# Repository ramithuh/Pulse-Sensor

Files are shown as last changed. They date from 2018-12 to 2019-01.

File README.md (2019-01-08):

#### EN1093 - Laboratory Practice - Group Project 



[https://blog.ramith.fyi/static/creating-a-pulse-sensor-from-scratch](https://blog.ramith.fyi/static/creating-a-pulse-sensor-from-scratch)

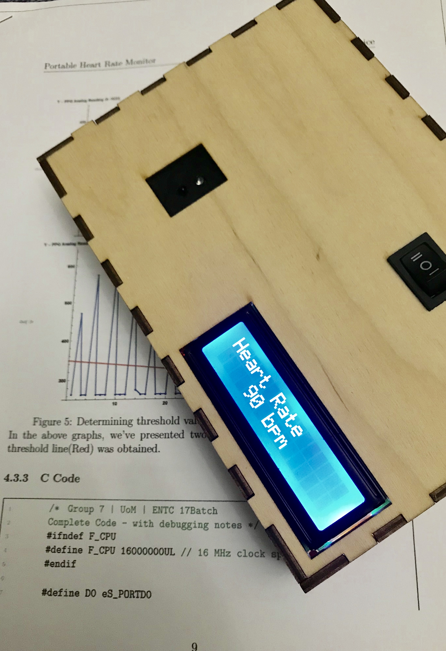
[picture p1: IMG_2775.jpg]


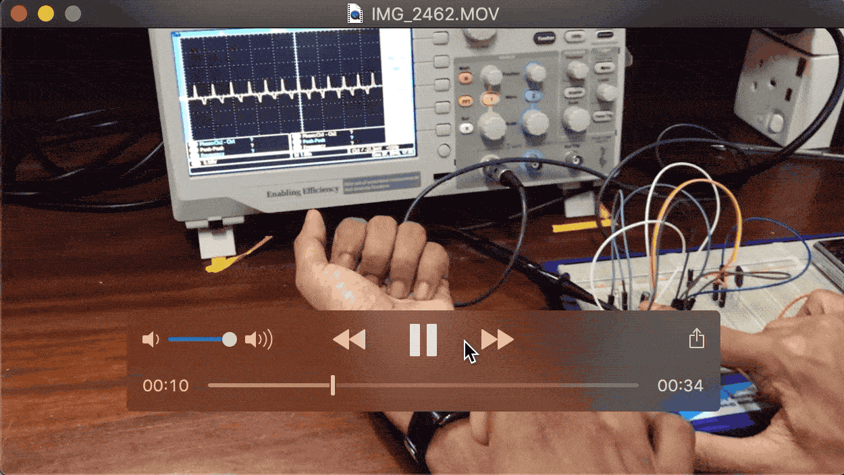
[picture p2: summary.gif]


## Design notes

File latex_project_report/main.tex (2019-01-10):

\documentclass[12pt]{article}
\usepackage[english]{babel}
\usepackage{natbib}
\usepackage{lipsum}
\usepackage{fontawesome}
\usepackage{hyperref}
\usepackage{circuitikz}
\usepackage{url}
\usepackage{placeins}
\usepackage[utf8x]{inputenc} 
\usepackage{amsmath}
\usepackage{graphicx}

\graphicspath{{images/}}
\usepackage{parskip}
\usepackage{fancyhdr}
\usepackage{vmargin}
\usepackage{wrapfig}
\usepackage{subfig}

\usepackage{siunitx}

\let\counterwithout\relax
\let\counterwithin\relax
\usepackage{chngcntr}

\usepackage[final]{pdfpages}
\usepackage[toc,page]{appendix}
\setmarginsrb{3 cm}{2.5 cm}{3 cm}{2.5 cm}{1 cm}{1.5 cm}{1 cm}{1.5 cm}

%%%%%%%% to embed code %%%%%%%%%%%%%%
\usepackage{listings}
\usepackage{color}

\definecolor{dkgreen}{rgb}{0,0.6,0}
\definecolor{gray}{rgb}{0.5,0.5,0.5}
\definecolor{mauve}{rgb}{0.58,0,0.82}
\lstset{
  language=Java,
  aboveskip=3mm,
  belowskip=3mm,
  showstringspaces=false,
  columns=flexible,
  basicstyle={\small\ttfamily},
  numberstyle=\tiny\color{gray},
  keywordstyle=\color{blue},
  commentstyle=\color{dkgreen},
  stringstyle=\color{mauve},
  breaklines=true,
  breakatwhitespace=true,
  tabsize=3,
  numbers=left,
  xleftmargin=2em,
  frame=single,
  framexleftmargin=1.5em
}

%%%%%%%% to embed code %%%%%%%%%%%%%%

\title{Portable Heart Rate Monitor}	% Title  
\author{EN1093 - Laboratory Practice}	%Author
\date{\today}						% Date

\makeatletter
\let\thetitle\@title
\let\theauthor\@author
\let\thedate\@date
\makeatother

\pagestyle{fancy}
\fancyhf{}
\rhead{\theauthor}
\lhead{\thetitle}
\cfoot{\thepage}

\begin{document}
\counterwithin{figure}{section}
\counterwithin{figure}{subsection}
%%%%%%%%%%%%%%%%%%%%%%%%%%%%%%%%%%%%%%%%%%%%%%%%%%%%%%%%%%%%%%%%%%%%%%%%%%%%%%%%%%%%%%%

\begin{titlepage}
	
	\centering
	
	\textsc{\small DEPARTMENT OF ELECTRONIC AND TELECOMMUNICATION ENGINEERING\\}
	\textsc{\small UNIVERSITY OF MORATUWA}\\[1.0 cm]
    \vspace*{0.5 cm}
    \\[1.5 cm]	% University Logo
    \textsc{\LARGE Group Project Report}\\[0.7 cm]	% University Name 
	\textsc{\Large EN1093 - Laboratory Practice}\\[0.5 cm]			% Course Code

	\rule{\linewidth}{0.2 mm} \\[0.4 cm]
	{ \huge \bfseries \thetitle}\\
	\rule{\linewidth}{0.2 mm} \\[1.5 cm]
	
	\begin{minipage}{0.4\textwidth}
		\begin{flushleft} \large
			\emph{Authors:}\\
			K.K. Herath\\
			H.M.U.D Herath\\
			R.U. Hettiarachchi\\
			M.N. Hettiaratchchi
			\end{flushleft}
			\end{minipage}~
			\begin{minipage}{0.4\textwidth}
			\begin{flushright} \large
			\emph{Registration Number:} \\
			170213V\\
			170215U\\
			170221T\\
			170222X
		\end{flushright}
	\end{minipage}\\[2 cm]
	 This is submitted as a partial fulfillment for the module EN1093\\[0.2 cm]
	 ---\\
	{\large \thedate}\\[2 cm]
	
	\vfill
	
\end{titlepage}

\newpage
\section{Abstract}
The proposed project measures the heart rate of a person using optical sensors. 
The optical sensor detects the variation of blood volume at the fingertip.
In this project's scope, the sensor will be an infrared light emitting diode (IR LED) which will be on the same side of the finger{(Reflective type \hyperref[sec:ppg]{PPG})\footnote{PPG Stands for photoplethysmogram. It measures the blood flow or blood pressure by optical means (typically involving measurement of changes in the transmission or scattering of light created by blood flow in a part of the body)\cite{PPG_meaning}.}.\\
The underlying principle is that the intensity of the reflected infrared light varies on the blood volume at an instance of the fingertip, which changes proportionately to each cardiac cycle. 
The lighting condition in the environment is very important to avoid distortion in the signal so we have taken the following measures,

• To design a special enclosure to cover the optical sensor for accurate measurements

• To use a band filter to remove unnecessary wavelengths.

Based on the refined output signal, an Atmel microcontroller was used to calculate and display the heart rate through the LCD Display.

\section{Acknowledgement}
We would like to express our gratitude to our supervisor Mr.Asanka Rathnayake for giving us technical advice and guidance.\\
Our sincere thanks goes to Mr.Thilina Sameera Ambagahawaththa for the inspiration and advice given to us to compile this report in \LaTeX.

We pay our gratitude to all the lecturers, instructors and other academic staff who intimately welcomed us to share their knowledge and experiences. We are very grateful to the personnel who are in charge of laboratories for allowing us to use the laboratories when needed and for the support given to solve technical problems.

%%%%%%%%%%%%%%%%%%%%%%%%%%%%%%%%%%%%%%%%%%%%%%%%%%%%%%%%%%%%%%%%%%%%%%%%%%%%%%%%%%%%%%%%
\newpage
\tableofcontents
\pagebreak
%%%%%%%%%%%%%%%%%%%%%%%%%%%%%%%%%%%%%%%%%%%%%%%%%%%%%%%%%%%%%%%%%%%%%%%%%%%%%%%%%%%%%%%%%

%%%%%%%%%%%%%%%%%%%%%%%%%%%%%%%%%%%%%%%%%%%%%%%%%%%%%%%%%%%%%%%%%%%%%%%%%%%%%%%%%%%%%%%%%
\section{Introduction}
Heart rate is the number of times one’s heart beats per minute.The portable heart rate monitor is a personal monitoring device that measures the heart rate in real time. For an average person this value lies between 60-100 bpm. The heart rate rises gradually during excercises and returns slowly to the rest value after excercise. The rate when the pulse returns to normal is an indication of fitness in a person.  Therefore a heart rate monitor is an essential device nowadays to keep in track with your body not only for someone who is suffering with heart diseases but also for a normal person to maintain fitness. Having a portable heart rate monitor makes it easy to carry it around when travelling. 
\\
In this project reflective photoplethysmogram(PPG) is used for heart rate monitoring. These sensors uses a light based technology to sense the rate of blood flow as controlled by the heart’s pumping action. This method is less sensitive to motion artifacts and therefore is user friendly.
\\

%%%%%%%%%%%%%%%%%%%%%%%%%%%%%%%%%%%%%%%%%%%%%%%%%%%%%%%%%%%%%%%%%%%%%%%%%%%%%%%%%%%%%%%%%

%%%%%%%%%%%%%%%%%%%%%%%%%%%%%%%%%%%%%%%%%%%%%%%%%%%%%%%%%%%%%%%%%%
\newpage
\section{Methodology}

	\begin{figure}[!htbp]  %this figure will be at the right
		\centering
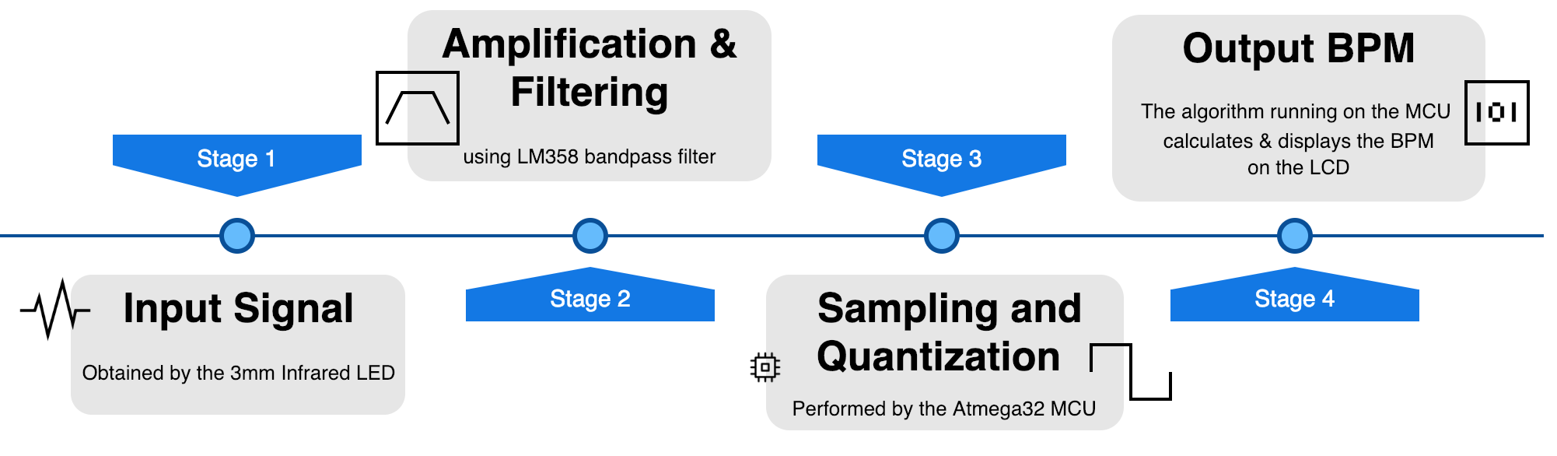
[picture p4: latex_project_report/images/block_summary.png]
		
		\caption{Methodology in a nutshell}
	\end{figure}

	\subsection{Sensor - (principle)}
	\label{sec:ppg}
	Reflection method was the method used in this project where the light emitted from the IR bulb is reflected by the blood vessel and the change in volume is therefore detected as reflected light by the photodiode.
	
	\begin{figure}[!htbp]  %this figure will be at the right

		\centering
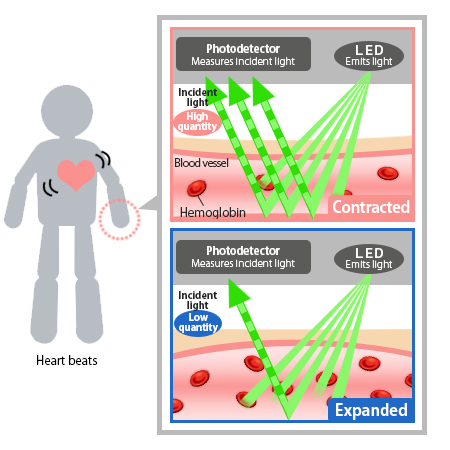
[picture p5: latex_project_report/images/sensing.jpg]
		
		\caption{How IR LED light is reflected from the blood vessels\cite{epson_sensor}}
	\end{figure}

		\subsection{Amplification and Filtering}
		
		To amplify the PPG signal we designed an amplifier circuit. However we observed that without proper filtering we cannot get a clear signal due to noise.
		So we had to determine the necessary values for the filter circuit.\\
		The typical heart rate of an adult is between 60-100bpm\cite{typical_pulse}.In frequency terms, these values correspond to the range 1-1.7 Hz.So an active bandpass filter circuit was designed to provide the following characteristics using LM358.

\subsubsection{Calculations}
\label{sec:4.2.1}
\begin{center}
	Cutoff frequency ($f$) = $\frac{1}{2\pi RC}$

	Upper cutoff frequency =$\ \frac{1}{2\pi ( 680\ k\si{\ohm}\ )( 100\ nF)}$ = 2.34051 Hz

	Lower cutoff frequency =$\ \frac{1}{2 \pi  ( 47\ k\si{\ohm})( 4.7\ \si{\micro}F)}$ = 0.720484 Hz
	\end{center}

	So we have a,

		\begin{itemize}
			\item Gain of 10
			\item Lower Cutoff Frequency of 0.72 Hz
			\item Upper Cutoff Frequency of 2.34 Hz\\
		  \end{itemize}
		 To have a low powered operational amplifier we selected LM358 integrated circuit.
	
		\begin{figure}[!htbp]
			
			\caption{Active bandpass filter for the pulse sensor\\}
			\textbf{Please Note: D2 should be flipped}
		\end{figure}

		\clearpage
	\subsection{Calculating BPM from the analog signal}
	The ATMega32 microcontroller was used to sample the analog signal to 0-1023 voltage levels. Then an algorithm was developed to identify peaks and thereby calculate the beats per minute. We used Atmel Studio to compile and flash the hex file to the microcontroller. 

	\subsubsection{Microcontroller}
	The ATmega32 is a low power high performance atmel AVR 8-bit microcontroller. 
			\begin{figure}[!htbp]
				\centering
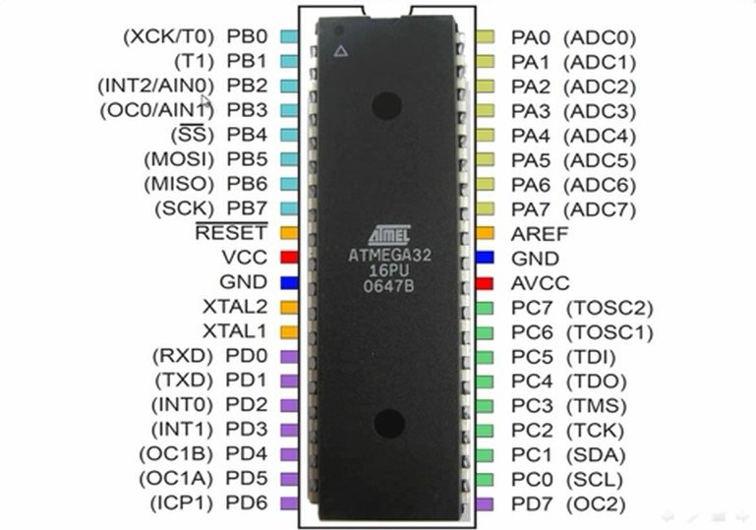
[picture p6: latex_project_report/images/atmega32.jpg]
				
				\caption{ATmega32 pinout}
			\end{figure}
	
	The AVR Minimum system board along with the AVR serial programmer was used to program the microcontroller.

	\subsubsection{Obtaining a threshold value}
	\label{sec:4.3.2}

		\begin{center}
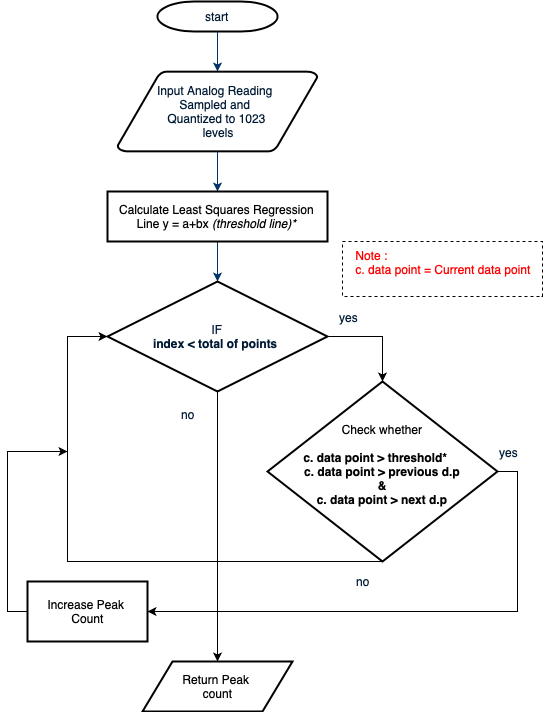
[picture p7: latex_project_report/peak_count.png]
		
		
		\end{center}	

	The above flowchart explains the peak counting algorithm with automatic threshold calculation. For calculating the threshold we're calculating the least squares regression line.
		
\subsubsection{Least Squares Regression Line }

``Least Squares line is a mathematical procedure for finding the best-fitting curve to a given set of points by minimizing the sum of the squares of the offsets ("the residuals") of the points from the curve. The sum of the squares of the offsets is used instead of the offset absolute values because this allows the residuals to be treated as a continuous differentiable quantity. However, because squares of the offsets are used, outlying points can have a disproportionate effect on the fit, \textbf{a property which may or may not be desirable depending on the problem at hand.}" 
\,- mathworld.wolfram.com\\Through the {MCU} algorithm the regression line parameters a and b were calculated
Sample regression line:
\begin{equation}
y = a + b x
\end{equation}

Sample slope:
\begin{equation}
b = \frac{\sum(x_i – \bar{x}) (y_i – \bar{y})} {\sum(x_i – \bar{x})^2}
\end{equation}

Sample intercept:
\begin{equation}
c = \bar{y} – b \bar{x}
\end{equation}

	\\
	
	\captionof{figure}{Determining threshold value line using simple linear regression}
\;
\;
\;
\;
\;
	In the above graphs, we've presented two data sets of two people and how the threshold line(Red) was obtained.

%% Calibration and Ambient Lighting conditions %% 

\subsection{Enclosure and PCB Design}
\begin{center}
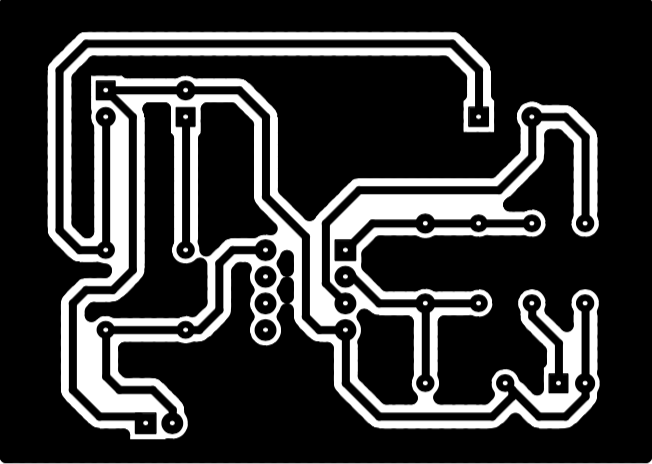
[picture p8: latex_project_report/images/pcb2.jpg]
	
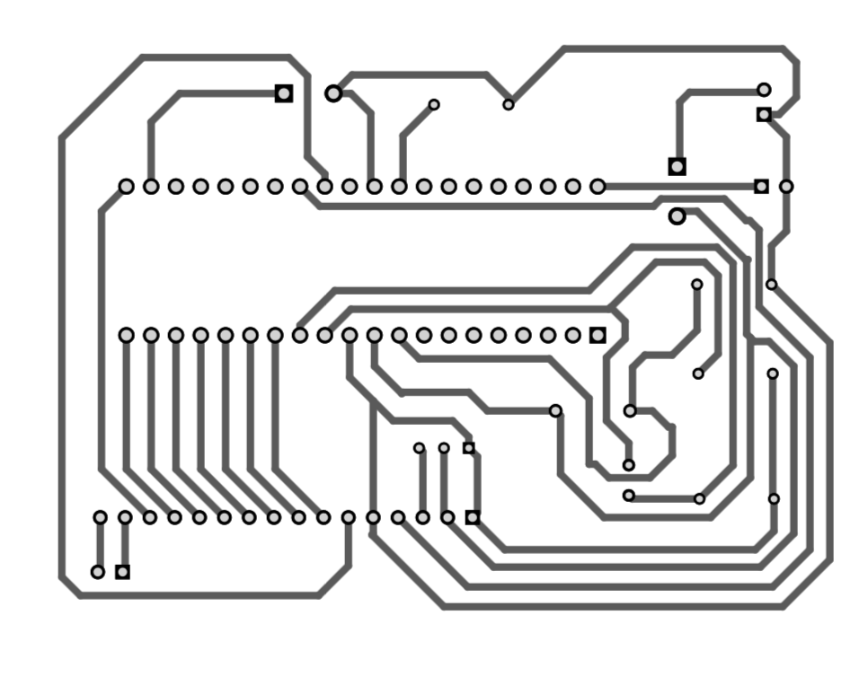
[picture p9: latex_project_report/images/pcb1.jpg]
	
	\captionof{figure}{PCB designed using altium}
\end{center}

\;\;\;

PCB designing must be done with care as the performance of the device depend on the reliability of the PCB. The schematic and the layout of the PCB was designed using Altium. Placement of components and routing was done manually. Components were mounted and soldered to the PCB and it was finalized by testing all the connections for short circuits and open circuits.\\
\;\;\;
The enclosure was designed using Autodesk AutoCAD software and it was laser cut as in figure\ref{fig:autodesk}. 

\begin{center}
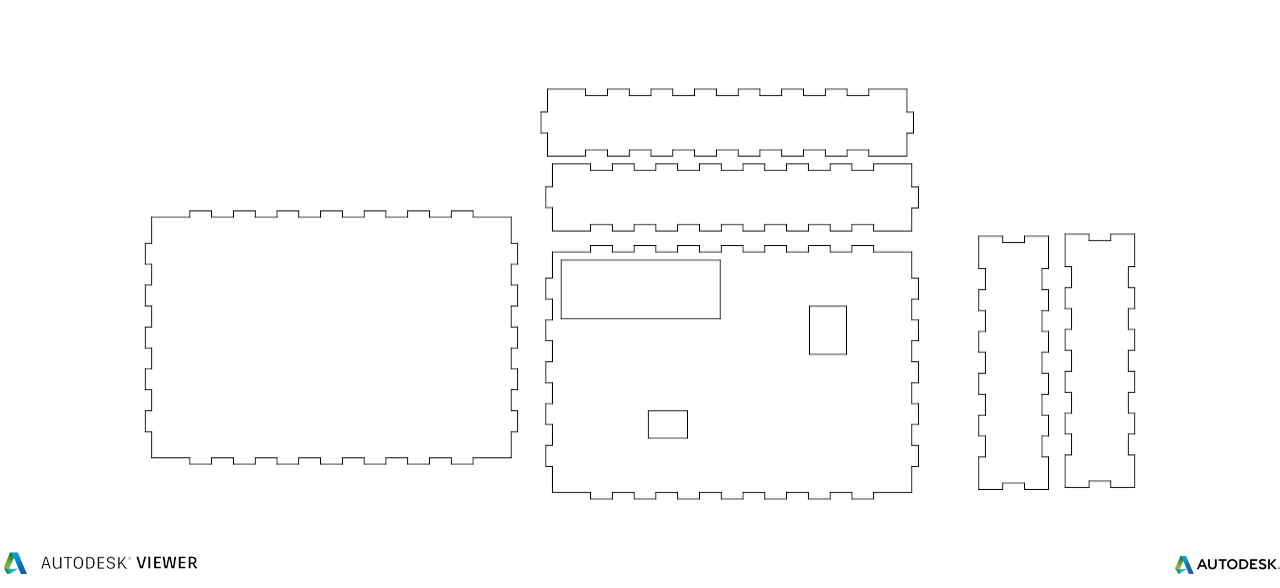
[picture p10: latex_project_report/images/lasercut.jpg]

\captionof{figure}{Laser Cut Design}
\label{fig:autodesk}

\end{center}

\newpage
\section{Implementation and Results}

\subsection{The effect of noise on the signal}
Initially our goal was to amplify the signal received from the photodiodes. Then we observed that we could not receive a clear amplified heartbeat signal as it gets suppressed by the 50Hz noise signal.

\subsubsection{Without the filter - Dominant 50Hz noise}

\begin{figure}[!htbp]
	\begin{tabular}{cc}
	\centering

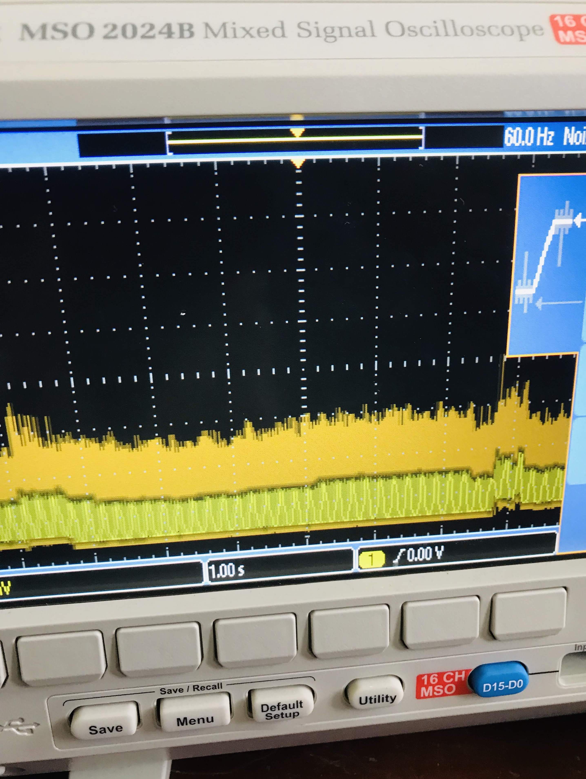
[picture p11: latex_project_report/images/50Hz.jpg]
	\subfloat[oscilloscope output]{}&
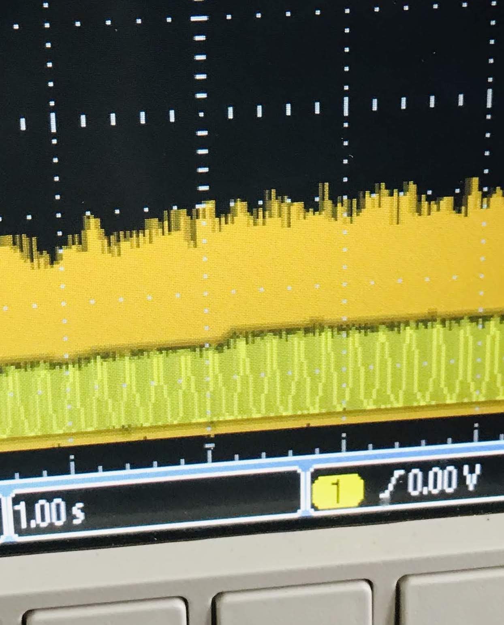
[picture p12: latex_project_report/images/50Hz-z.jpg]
\subfloat[zoomed view]{}\\

	\end{tabular}
\end{figure}

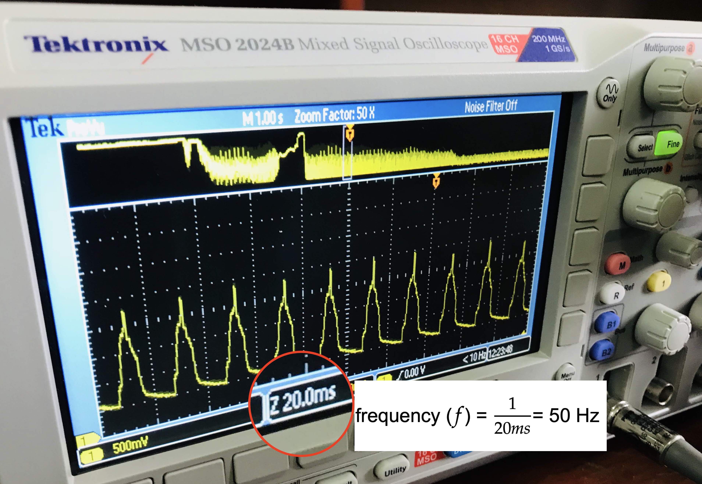
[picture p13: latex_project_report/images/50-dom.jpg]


\subsubsection{With the active bandpass filter}
The initial circuit was modified into an active bandpass filter circuit by calculating the necessary values as shown in \hyperref[sec:4.2.1]{4.2.1}.Next, using the signal generator, the characteristics of our filter circuit from the digital oscilloscope was observed. The responses were as follows;\\ Observation: The amplitudes of the frequencies at the cut off frequencies were gradually reduced.\footnote{The required range of frequencies 50-140bpm (0.83 - 2.33Hz) were passed without much attenuation}

\begin{figure}[h]
 
	\begin{tabular}{ccc}

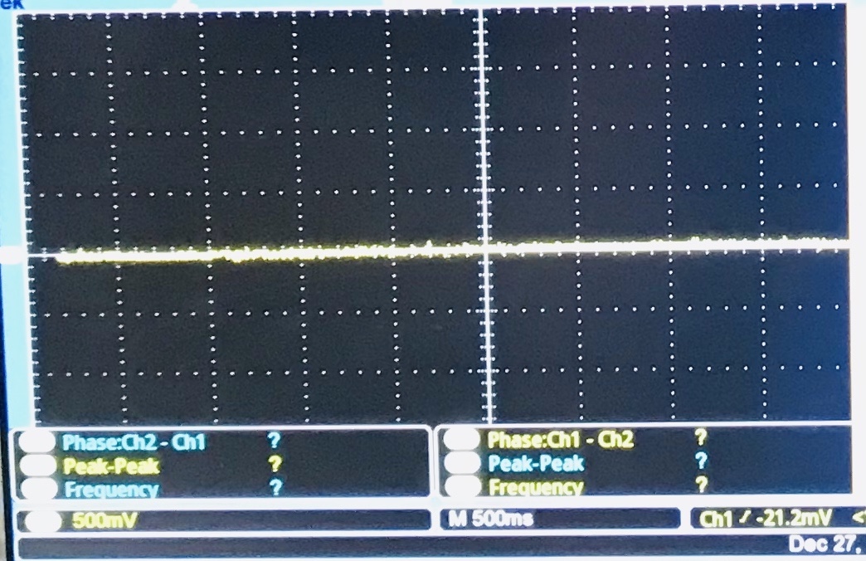
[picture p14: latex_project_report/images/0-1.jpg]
\subfloat[0.1Hz]{}&
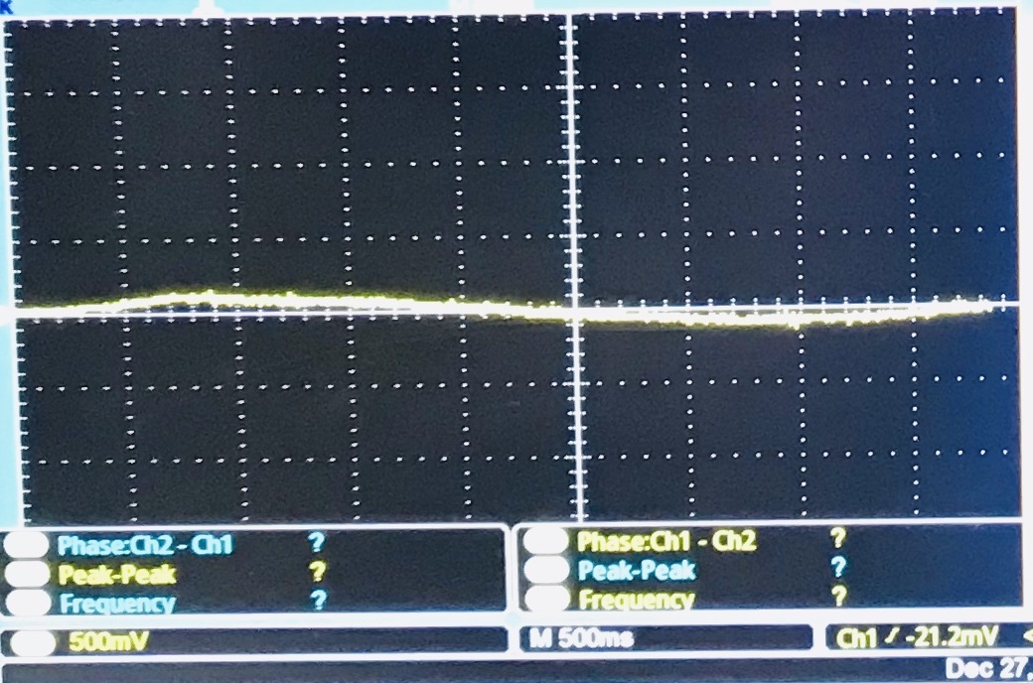
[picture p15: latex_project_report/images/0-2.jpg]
\subfloat[0.2Hz]{}&
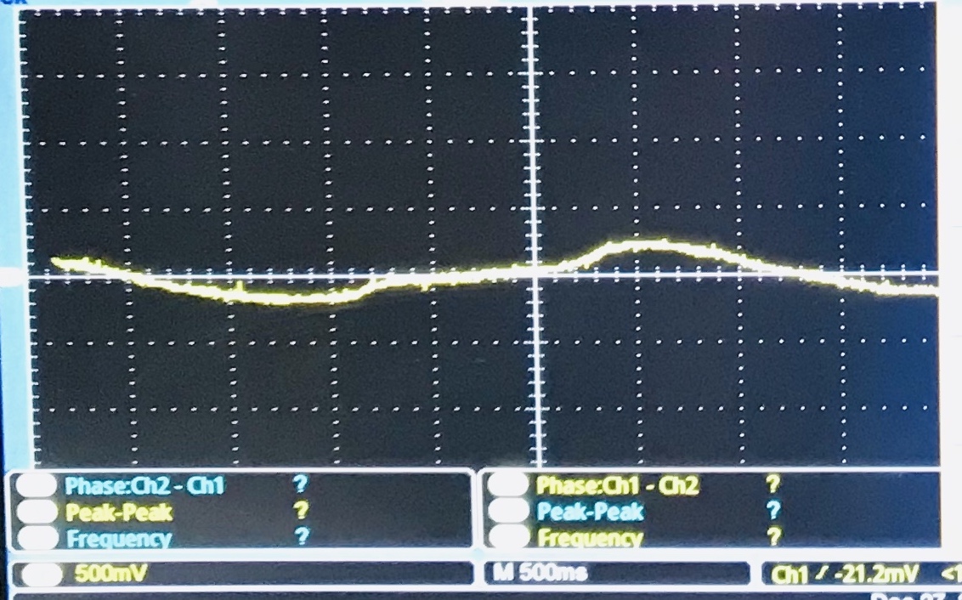
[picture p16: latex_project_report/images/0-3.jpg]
\subfloat[0.3Hz]{}\\

\end{tabular}
\end{figure}

\begin{figure}[h]
	\ContinuedFloat*
	\begin{tabular}{ccc}

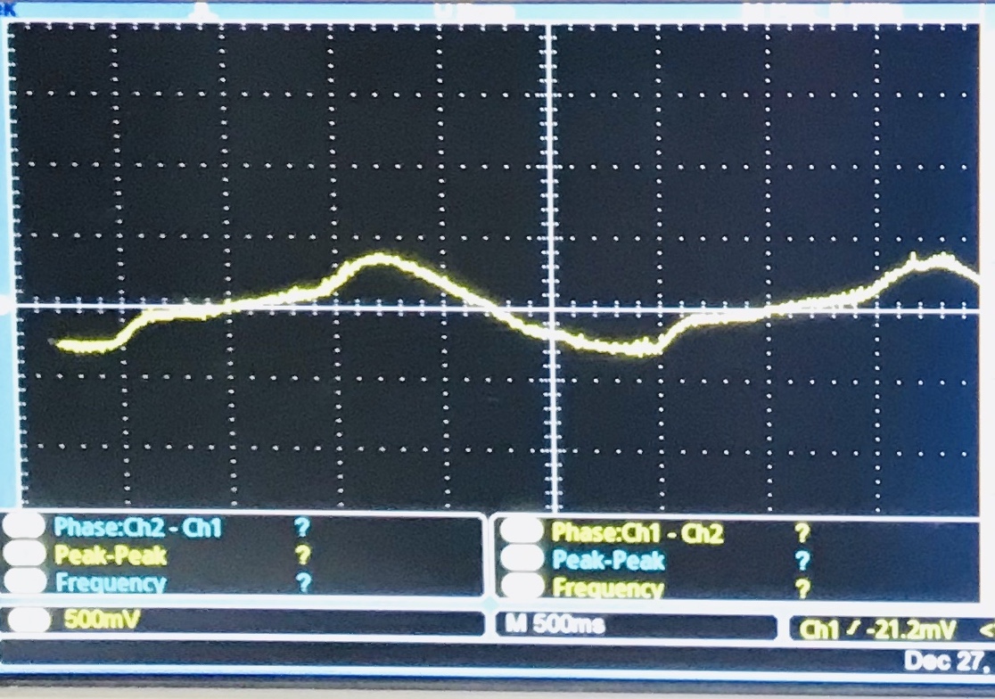
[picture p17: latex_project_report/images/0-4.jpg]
\subfloat[0.4Hz]{}&
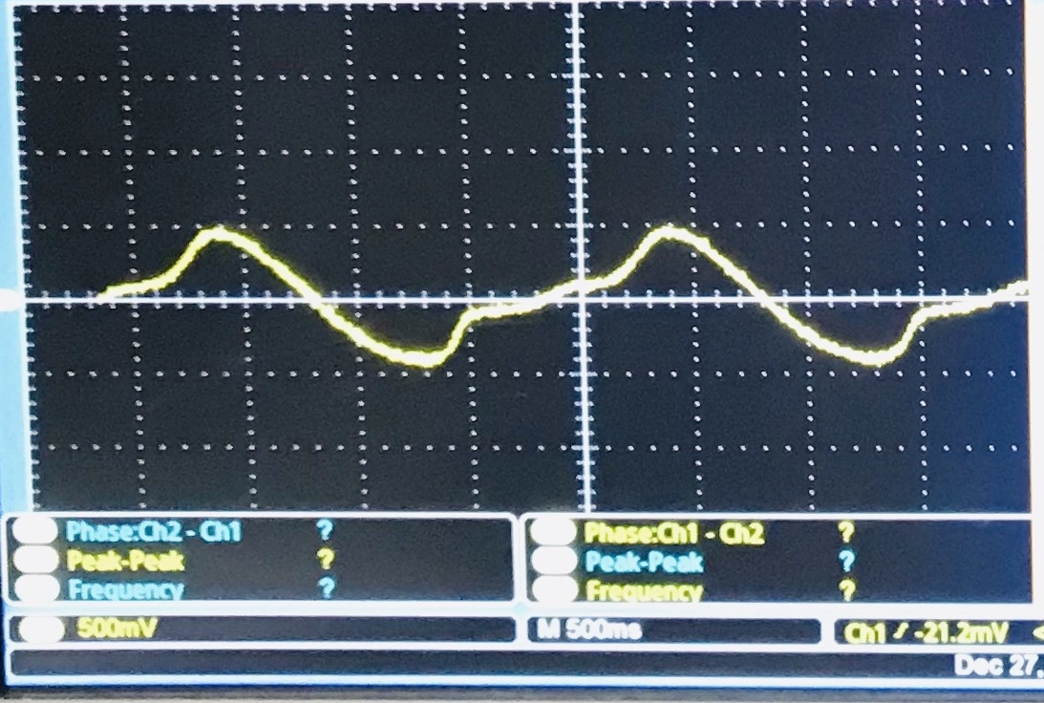
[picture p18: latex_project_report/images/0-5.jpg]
\subfloat[0.5Hz]{}&
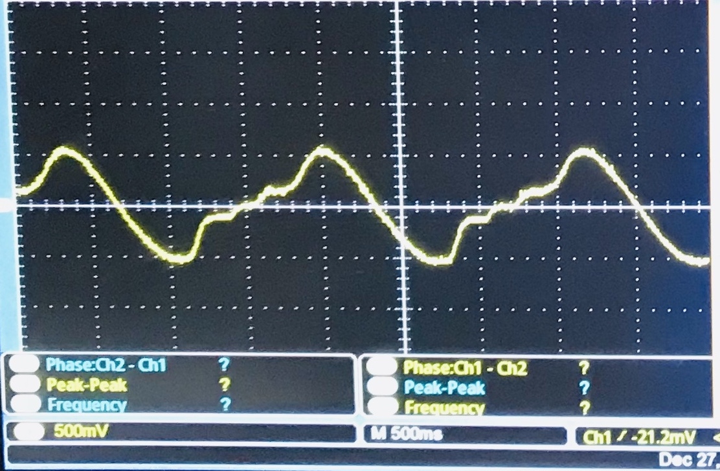
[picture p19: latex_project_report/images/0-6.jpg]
\subfloat[0.6Hz]{}\\

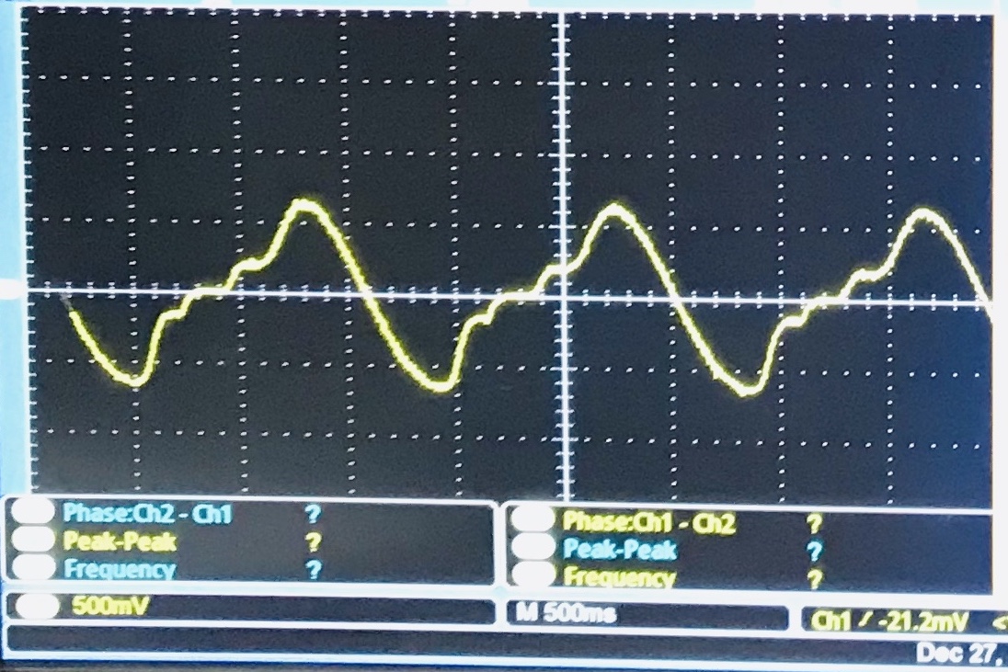
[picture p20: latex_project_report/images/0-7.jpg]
\subfloat[0.7Hz]{}&
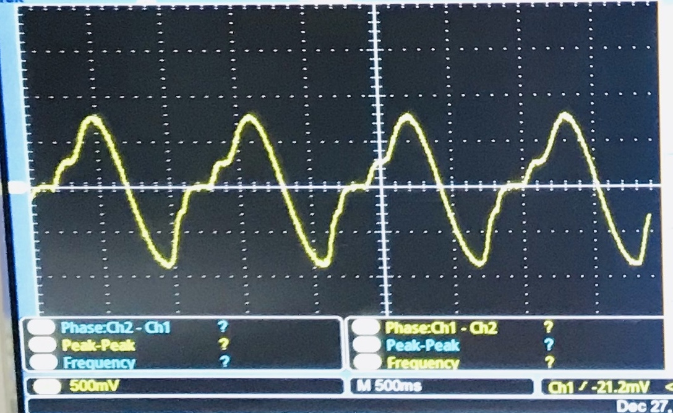
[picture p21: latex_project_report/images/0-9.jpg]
\subfloat[0.9Hz]{}&
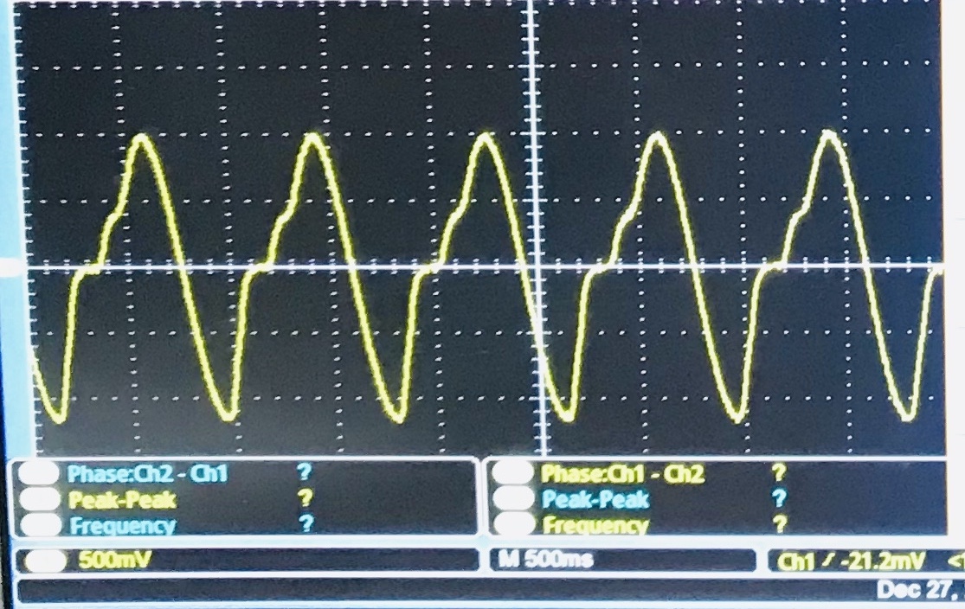
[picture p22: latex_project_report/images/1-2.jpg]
\subfloat[1.2Hz ]{}\\

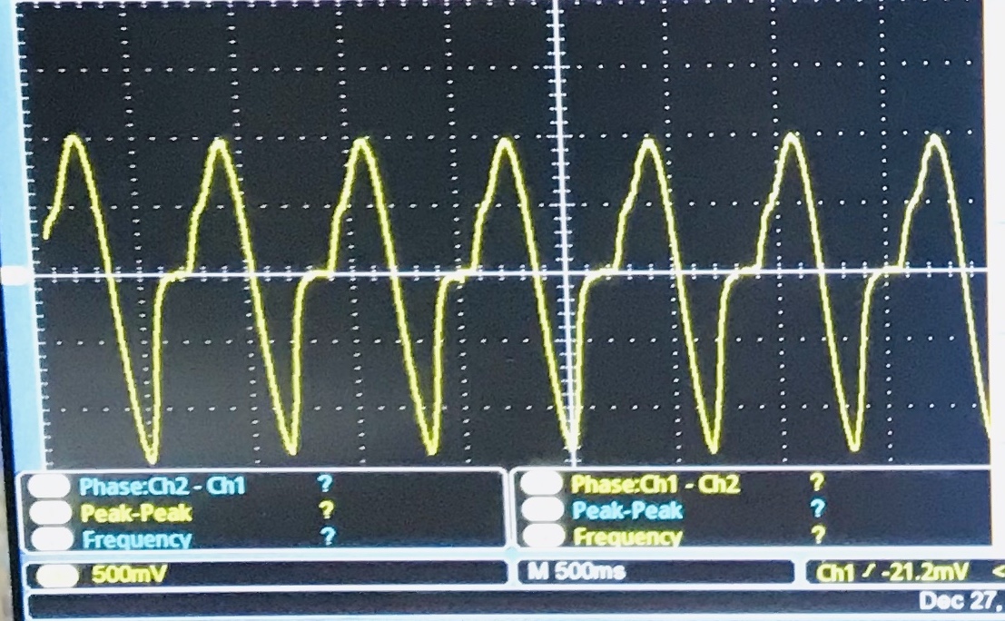
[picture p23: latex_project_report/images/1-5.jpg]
\subfloat[1.5Hz]{}&
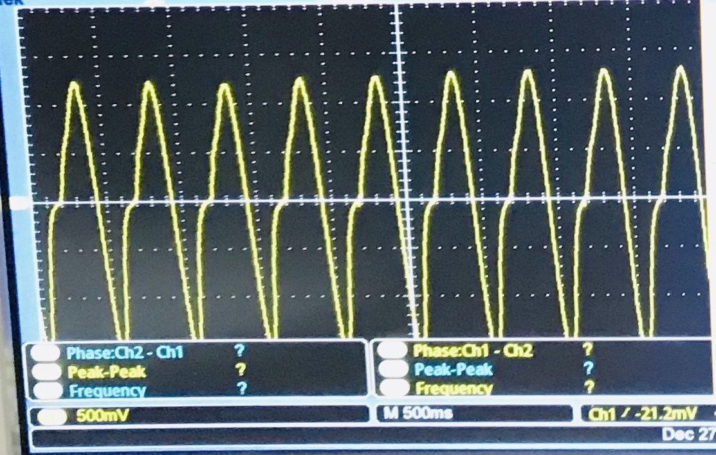
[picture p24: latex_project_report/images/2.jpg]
\subfloat[2Hz]{}&
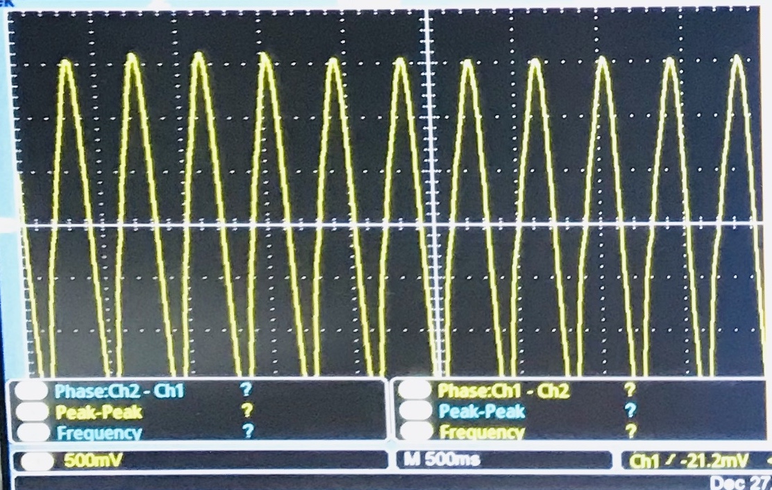
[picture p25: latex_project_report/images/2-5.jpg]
\subfloat[2.5Hz]{}\\

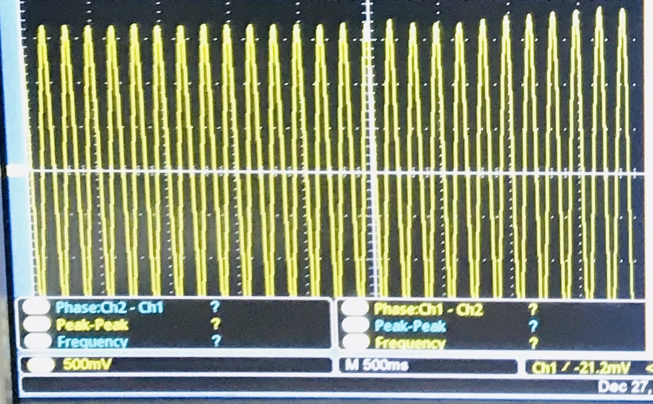
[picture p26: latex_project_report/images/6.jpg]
\subfloat[6Hz]{}&
\subfloat[10Hz]{}&
\subfloat[15Hz]{}\\

\end{tabular}
\caption{Frequency response of the bandpass filter}
	\end{figure}
\clearpage

By the observations above we were able to verify that the response of this circuit can be given by the graph below:
\begin{center}


\end{center}
\subsubsection{Obtaining a threshold value}

During testing, it was observed that due to ambient lighting conditions and movement of the patients’ finger placement between the LED and photodiode sudden amplitude changes can occur. 

It was evident that a hardcoded threshold value will not count the number of peaks accurately. Therefore, the calibration algorithm which was explained in \hyperref[sec:4.3.2]{4.3.2} determines a threshold value per session.

\begin{figure}[!htbp]
	
	\begin{tabular}{ccc}
\subfloat[Varying amplitudes]{}&
\subfloat[Amplitude Gradually decreasing]{}\\
	\end{tabular}
	\end{figure}

	\begin{center}
	
		
		\caption{How PPG varies according to positions\cite{analomy_pulse_sensor}}
	\end{center}

\label{sec:results}

\subsubsection{Accuracy Measurement}
The accuracy of this device was measured by comparing the values measured with a HUAWEI Color Band A2.
According to the measured values the accuracy of our device was 78\% with an error margin of ±3bpm.

\begin{figure}[!htbp]
 
	\begin{tabular}{cc}

\subfloat{}&
\subfloat{}\\

\end{tabular}
\caption{Tests performed to assess the accuracy}
\end{figure}

\clearpage

\newpage
\section{Discussion}
Using PPG we were able to monitor the heart rate with much accuracy and it seemed to be an easy method to be used for portable heart rate monitors. Since frequency of the analog waveform of the pulse that we receive of a person doesn’t exceed 2Hz the sampling frequency of 5Hz that we have used in this project seem to give the most accurate results. 
\\
Noise is the main issue that many faces when receiving analog signals and we were able to overcome that issue with the use of an appropriate active bandpass filter. The most difficult part of the project was to convert the analog signal to a digital signal. Here we used a square regression line as the threshold and then counted the peaks.
\\
We used IR sensors to get the input signal from the fingertip, but it seems that using a green light PPG sensor will give a better input signal. Also, with the use of a smaller in size enclosure the heart rate monitor would be more convenient as a compatible device.
\\
As an improvement the use of a more advanced sensor would make this device output more accurate results.

\newpage
\section{Our repository}
For further study, we have opensourced this project on Github. All the diagrams, schematics, PCB designs and even our tex files can be found through our repository.\\\\
\faGithub\href{https://github.com/ramithuh/Pulse-Sensor}{ https://github.com/ramithuh/Pulse-Sensor}.
\\
\begin{center}
	
\end{center}

\newpage
%	Bibliography

%----------------------------------------------------------------------------------------
\bibliography{biblist}{}
\bibliographystyle{plain}

\newpage
\section{Appendices - }
\subsection{MCU Sourcecode in C}
\begin{lstlisting}
	/*  Group 7 | UoM | ENTC 17Batch  
	Complete Code - with debugging notes */
	#ifndef F_CPU
	#define F_CPU 16000000UL // 16 MHz clock speed
	#endif
	
	#define D0 eS_PORTD0
	#define D1 eS_PORTD1
	#define D2 eS_PORTD2
	#define D3 eS_PORTD3
	#define D4 eS_PORTD4
	#define D5 eS_PORTD5
	#define D6 eS_PORTD6
	#define D7 eS_PORTD7
	#define RS eS_PORTC6
	#define EN eS_PORTC7
	
	#include <avr/io.h>
	#include <util/delay.h>
	#include "stdlib.h"
	#include "string.h"
	#include "lcd.h"
	
	char disp[16]="0000000000000001";
	char result[8] = "00000001"; 

	void lcd_disp(char data_points[],int r,int c,char w[]){ 
	
		if(w=="clear")Lcd8_Clear();
		Lcd8_Set_Cursor(r,c);
		Lcd8_Write_String(data_points);
	}
	
	void ADC_Init(){
		DDRA=0x0;			/* Make ADC port as input */
		ADCSRA = 0x87;			/* Enable ADC, fr/128  */
		ADMUX = 0x40;			/* Vref: Avcc, ADC channel: 0 */
	}
	
	int ADC_Read(char channel){
		int Ain,AinLow;
		
		ADMUX=ADMUX|(channel & 0x0f);	/* Set input channel to read */
	
		ADCSRA |= (1<<ADSC);		/* Start conversion */
		while((ADCSRA&(1<<ADIF))==0);	/* Monitor end of conversion interrupt */
		_delay_us(10);
		AinLow = (int)ADCL;		/* Read lower byte*/
		Ain = (int)ADCH*256;		/* Read higher 2 bits and 
						Multiply with weight */
		Ain = Ain + AinLow;				
		return(Ain);			/* Return digital value*/
	}
	
	/*************** threshold ***************/
	double m=0,c=0; // gradient and slope
	
	double sumit(int data_points[],int length){
		 int i;
		 double sum=0;
		 for(int i=1;i<=length;i++)sum+=data_points[i];
	
		 return sum;
	}
	
	double xysum(int data_points[],int length){
		 int i;
		 double sum=0;
		 for(int i=1;i<=length;i++)sum+=(i)*data_points[i];
	
		 return sum;
	}
	
	void regression(int data_points[],double n){
		double squarex= (n)*(n+1)*(2*n+1)/6.0;
		double xbar = (n+1)/2.0;
		double ybar = sumit(data_points,n)/n;
	
		m=(xysum(data_points,n)- n*xbar*ybar)/( squarex - n*xbar*xbar );
		c=ybar-m*xbar;
	}
	/*************** end threshold ***************/

	int main(void){
		DDRD = 0xFF;  // #
		DDRC = 0xFF;  //for lcd
		DDRA = 0x00;  //Analog input

		ADC_Init();

		Lcd8_Init(); //Initializing the LCD screen
		lcd_disp("Starting Pulse ~)",1,0,"");
		lcd_disp("Sensor *_*",2,0,"");
	
		_delay_ms(1000);
		
		lcd_disp("Place your",1,0,"clear");
		lcd_disp("fingertip",2,0,"");
		_delay_ms(2000);
		
		lcd_disp("Keep placing ~",1,0,"clear");
		lcd_disp("your fingertip",2,0,"");
		
		_delay_ms(3000);
		int i;
		int thresh=300;
		int count=0;
		int count2=0; //modified peak counting algo

		/*  timing data */
			double sampling_rate = 0.100 ;	   	// actually this is the _delay_ms val
			int time_limit = 10 ;  				 //in seconds
			int se=time_limit/(sampling_rate*2);
			int data_points[se+1];
	
		data_points[0]=0;
		/* /timing data */

		/* for debugging purposes -> h and l records the peaks */
		int h=0;
		int l=1023;
		
		char val[6]; //temporary variable for itoa

		for(i=0;i<time_limit/(sampling_rate*2);i++){	
			data_points[i+1]=ADC_Read(0);
			
			itoa(data_points[i+1],val,10);
			//lcd_disp(val,1,0,"");
			lcd_disp("Measuring.. *_*",1,0,"clear");
			
			int k=16*(data_points[i+1]-200)/375;
			
			char anim[16]="";
			
			int h=0;
			for(h=0;h<k;h++){
				anim[h]='~';
			}
			itoa(k,val,10);
			lcd_disp(anim,2,0,"");
			_delay_ms(sampling_rate*1000);
		
		}

		regression(data_points,se);
	
		//recorded wave form
		for(i=0;i<time_limit/(sampling_rate*2);i++){	
			thresh=(i+2)*m+c;
	
			int a=data_points[i+1];//current value
			char temp[11]="";
			char ccount[3];
	
			if(a>h)h=a; //max peak
			if(a<l)l=a; //min peak
			
			if(a>thresh){
				count+=1; //peak counting]
				if(a>data_points[i] && a>data_points[i+2]){
					count2+=1;
				}
				
			}

		}

		//displaying the heart rate
		char bpm[10]="Heart Rate : ";

		lcd_disp(bpm,1,0,"clear");
		
		itoa(count2*(60/time_limit),val,10);
	
		strcat(val," bpm");
		lcd_disp(val,2,4,"");

	}
\end{lstlisting}
	Based on this \cite{avr_analog} and this data-sheet \cite{atmega32_datasheet}

\subsection{Mathematica Simulations}


\newpage


\newpage
\subsection{MCU Schematic}


\newpage
\subsection{ATmega32 Datasheet - Summary}


\end{document}

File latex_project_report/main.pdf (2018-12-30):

DEPARTMENT OF ELECTRONIC AND TELECOMMUNICATION

ENGINEERING

UNIVERSITY OF MORATUWA


Group Project Report

EN1093 - Laboratory Practice

# Portable Heart Rate Monitor

### Authors: K.K. Herath H.M.U.D Herath R.U. Hettiarachchi M.N. Hettiaratchchi

### Registration Number:

170213V
170215U
170221T
170222X

This is submitted as a partial fulfillment for the module EN1093

—

### December 30, 2018

Portable Heart Rate Monitor | EN1093 - Laboratory Practice

## 1 Abstract

The proposed project measures the heart rate of a person using optical sensors. The optical sensor detects the variation of blood volume at the fingertip. In our project the sensor will be an infrared light emitting diode (IR LED) which will be on the same side of the finger. The underlying principle is that the intensity of the reflected infrared light varies on the blood volume at an instance of the fingertip, which changes proportionately to each cardiac cycle. The lighting condition in the environment is very important to avoid distortion in the signal so we have taken the following measures,

- To design a special enclosure to cover the optical sensor for accurate measurements
- To use a band filter to remove unnecessary wavelengths.

Based on the refined output signal, we used an Atmel microcontroller to calculate and display the heart rate through the LCD Display.

## 2 Acknowledgement

We would like to express our gratitude to our supervisor Mr.Asanka Rathnayake for giving us technical advice and guidance.
Our sincere thanks goes to Mr.Thilina Sameera Ambagahawaththa for the inspiration and advice given to us to compile this report in LaTeX.

We pay our gratitude to all the lecturers, instructors and other academic staff who intimately welcomed us to share their knowledge and experiences. We are very grateful to the personnel who are in charge of laboratories for allowing us to use the laboratories when needed and for the support given to solve technical problems.

1

Portable Heart Rate Monitor | EN1093 - Laboratory Practice

## Contents

1 Abstract | 1
2 Acknowledgement | 1
3 Introduction | 3
4 Methodology | 4
5 Implementation and Results | 10
6 Discussion | 13
7 Online Materials | 14

2

Portable Heart Rate Monitor | EN1093 - Laboratory Practice

## 3 Introduction

This is a simple report template with the UCT logo. Feel free to use/modify it to suit your needs. Variables that need to be altered have been commented to make modifications easier. For example if you need to change the university logo, look for the comment % University Logo in this file and then make appropriate modifications in that line. A Table of Contents and a bibliography have also been implemented. To add entries to your bibliography, simply edit biblist.bib in the root folder and then use the \cite{...} command in main.tex [4]. The Table of Contents will be updated automatically. I hope that you find this template both visually appealing and useful.
— Linus

3

Portable Heart Rate Monitor | EN1093 - Laboratory Practice

## 4 Methodology

The methodology can be summarized to the following block diagram.

### 4.1 Sensor

Fusce mauris. Vestibulum luctus nibh at lectus. Sed bibendum, nulla a faucibus semper, leo velit ultricies tellus, ac venenatis arcu wisi vel nisl. Vestibulum diam. Aliquam pellentesque, augue quis sagittis posuere, turpis lacus congue quam, in hendrerit risus eros eget felis. Maecenas eget erat in sapien mattis porttitor. Vestibulum porttitor. Nulla facilisi. Sed a turpis eu lacus commodo facilisis. Morbi fringilla, wisi in dignissim interdum, justo lectus sagittis dui, et vehicula libero dui cursus dui. Mauris tempor ligula sed lacus. Duis cursus enim ut augue. Cras ac magna. Cras nulla. Nulla egestas. Curabitur a leo. Quisque egestas wisi eget nunc. Nam feugiat lacus vel est. Curabitur consectetuer.


Figure 1: How IR LED light is reflected from the blood vessels

4

Portable Heart Rate Monitor | EN1093 - Laboratory Practice

### 4.2 Amplification and Filtering

To amplify the PPG signal we designed an amplifier circuit. However we observed that without proper filtering we cannot get a clear signal due to noise. So we had to determine the necessary values for the filter circuit.
The typical heart rate of an adult is between 60-100bpm[3].In frequency terms, these values correspond to the range 1-1.7 Hz.So an active bandpass filter circuit was designed to provide the following characteristics using LM358.

### 4.2.1 Calculations

Cutoff frequency (f) = 1
2πRC
Lower cutoff frequency = | 1
2π(680 kΩ )(100 nF) = 2.34051 Hz
Upper cutoff frequency = | 1
2π(47 kΩ)(4.7 µF) = 0.720484 Hz

So we have,

- Gain of 10
- Lower Cutoff Frequency of 0.72 Hz
- Upper Cutoff Frequency of 2.34 Hz

To have a low powered operational amplifier we selected LM358 integrated circuit.

5


Figure 2: Active bandpass filter for the pulse sensor

Portable Heart Rate Monitor | EN1093 - Laboratory Practice

### 4.3 Calculating BPM from the analog signal

The ATMega32 microcontroller was used to sample the analog signal to 0-1023 voltage levels. Then an algorithm was developed to identify peaks and thereby calculate the beats per minute. We used Atmel Studio to compile and flash the hex file to the microcontroller.

### 4.3.1 Microcontroller

The ATmega32 is a low power high performance atmel AVR 8-bit microcontroller.


Figure 3: ATmega32 pinout

### 4.3.2 Obtaining a threshold value

Give basic info on how threshold was determined.

### 4.3.3 Algorithm

can include the flowchat, and code here

1 | /* Group 7 | UoM | ENTC 17Batch */
2 | #ifndef F_CPU
3 | #define F_CPU 16000000UL // 16 MHz clock speed
4 | #endif

7

Portable Heart Rate Monitor | EN1093 - Laboratory Practice
5 | #define D0 eS_PORTD0
6 | #define D1 eS_PORTD1
7 | #define D2 eS_PORTD2
8 | #define D3 eS_PORTD3
9 | #define D4 eS_PORTD4
10 | #define D5 eS_PORTD5
11 | #define D6 eS_PORTD6
12 | #define D7 eS_PORTD7
13 | #define RS eS_PORTC6
14 | #define EN eS_PORTC7

15
16 | #include <avr/io.h>
17 | #include <util/delay.h>
18 | #include "stdlib.h"
19 | #include "string.h"
20 | #include "lcd.h"

21
22 | char disp[16]="0000000000000001";
23 | char result[8] = "00000001";

24
25 | void lcd_disp(char arr[],int r,int c,char w[]){
26 | if(w=="clear")Lcd8_Clear();
27 | Lcd8_Set_Cursor(r,c);
28 | Lcd8_Write_String(arr);
29 | }

30
31 | void ADC_Init(){
32 | DDRA=0x0; | /* Make ADC port as input */
33 | ADCSRA = 0x87; | /* Enable ADC, fr/128 */
34 | ADMUX = 0x40; | /* Vref: Avcc, ADC channel: 0 */
35 | }

36
37 | int ADC_Read(char channel){
38 | int Ain,AinLow;

39
40 | ADMUX=ADMUX|(channel & 0x0f); /* Set input channel to read */

41
42 | ADCSRA |= (1<<ADSC); | /* Start conversion */
43 | while((ADCSRA&(1<<ADIF))==0); /* Monitor end of conversion
interrupt */
44 | _delay_us(10);
45 | AinLow = (int)ADCL; | /* Read lower byte*/
46 | Ain = (int)ADCH*256; | /* Read higher 2 bits and

8

Portable Heart Rate Monitor | EN1093 - Laboratory Practice
47 | Multiply with weight */
48 | Ain = Ain + AinLow;
49 | return(Ain); | /* Return digital value*/
50 | }

51

52

53
54 | int main(void){

55
56 | DDRD = 0xFF; // #
57 | DDRC = 0xFF; //for lcd
58 | DDRA = 0x00; //Analog input

59
60 | ADC_Init();

61
62 | Lcd8_Init(); //Initializing the LCD screen
63 | lcd_disp("Starting Pulse ~)",1,0,"");
64 | lcd_disp("Meter",2,0,"");

65
66 | _delay_ms(3000);
67 | int i;

68
69 | for(i=0;i>=0;i++){

70
71 | char temp[11]="Analog - ";
72 | char val[4]; // 0 - 255 value

73
74 | itoa(ADC_Read(0),val,10);

75
76 | strcat(temp,val);

77
78 | lcd_disp(temp,1,0,"clear");
79 | _delay_ms(300);

80

81 | }
82 | }

Based on this [1] and this data-sheet [2]

### 4.4 Enclosure and PCB Design

9

Portable Heart Rate Monitor | EN1093 - Laboratory Practice

## 5 Implementation and Results

### 5.1 The effect of noise on the signal

### 5.1.1 Without the filter

blah blah blaaah

### 5.1.2 With the active bandpass filter

### 5.1.3 Obtaining a threshold value

While testing, we observed that due to various lighting conditions, the amplitude of the output waveform varies. Therefore we came to a conclusion that a hardcoded threshold value will not count the number of peaks accurately. Therefore, we implemented a calibration algorithm.


(a) Variying amplitudes | (b) Amplitude Gradually decreasing

10

Portable Heart Rate Monitor | EN1093 - Laboratory Practice


Figure 4: Filtered Waveform

11

Portable Heart Rate Monitor | EN1093 - Laboratory Practice

Lorem ipsum dolor sit amet, consectetuer adipiscing elit. Ut purus elit, vestibulum ut, placerat ac, adipiscing vitae, felis. Curabitur dictum gravida mauris. Nam arcu libero, nonummy eget, consectetuer id, vulputate a, magna. Donec vehicula augue eu neque. Pellentesque habitant morbi tristique senectus et netus et malesuada fames ac turpis egestas. Mauris ut leo. Cras viverra metus rhoncus sem. Nulla et lectus vestibulum urna fringilla ultrices. Phasellus eu tellus sit amet tortor gravida placerat. Integer sapien est, iaculis in, pretium quis, viverra ac, nunc. Praesent eget sem vel leo ultrices bibendum. Aenean faucibus. Morbi dolor nulla, malesuada eu, pulvinar at, mollis ac, nulla. Curabitur auctor semper nulla. Donec varius orci eget risus. Duis nibh mi, congue eu, accumsan eleifend, sagittis quis, diam. Duis eget orci sit amet orci dignissim rutrum.

12

Portable Heart Rate Monitor | EN1093 - Laboratory Practice

## 6 Discussion

Nam dui ligula, fringilla a, euismod sodales, sollicitudin vel, wisi. Morbi auctor lorem non justo. Nam lacus libero, pretium at, lobortis vitae, ultricies et, tellus. Donec aliquet, tortor sed accumsan bibendum, erat ligula aliquet magna, vitae ornare odio metus a mi. Morbi ac orci et nisl hendrerit mollis. Suspendisse ut massa. Cras nec ante. Pellentesque a nulla. Cum sociis natoque penatibus et magnis dis parturient montes, nascetur ridiculus mus. Aliquam tincidunt urna. Nulla ullamcorper vestibulum turpis. Pellentesque cursus luctus mauris.

13

Portable Heart Rate Monitor | EN1093 - Laboratory Practice

## 7 Online Materials

The project has been open sourced on Github. All the diagrams, schematics, PCB designs can be found through our repository.

https://github.com/ramithuh/Pulse-Sensor.

14

Portable Heart Rate Monitor | EN1093 - Laboratory Practice

## References

[1] Analog | readings | with | avr. | https://maker.pro/custom/tutorial/
how-to-take-analog-readings-with-an-avr-microcontroller. (https://maker.pro/custom/tutorial/how-to-take-analog-readings-with-an-avr-microcontroller) | Accessed:
2018-12-28.
[2] Atmega32 datasheet. http://ww1.microchip.com/downloads/en/devicedoc/doc2503.pdf. (http://ww1.microchip.com/downloads/en/devicedoc/doc2503.pdf) Accessed: 2018-11-02.
[3] Harvard heart letter. https://www.health.harvard.edu/heart-health/want-to-check-your-heart-rate-heres-how. (https://www.health.harvard.edu/heart-health/want-to-check-your-heart-rate-heres-how) Accessed: 2018-12-30.
[4] Photoplethysmogram - wikipedia article. https://en.wikipedia.org/wiki/Photoplethysmogram. (https://en.wikipedia.org/wiki/Photoplethysmogram) Accessed: 2018-10-12.

15

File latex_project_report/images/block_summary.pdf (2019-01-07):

Stage 1; Stage 3; Stage 2; Stage 4 Input Signal; Obtained by the 3mm Infrared LED; Amplification & Filtering; using LM358 bandpass filter; Sampling and Quantization; Performed by the Atmega32 MCU; Output BPM; The algorithm running on the MCU calculates & displays the BPM on the LCD

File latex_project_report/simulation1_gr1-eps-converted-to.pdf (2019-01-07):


10 | 20 | 30 | 40 | 50

# X - Time

300

350

400

450

# Y - PPG Analog Reading (0-1023)

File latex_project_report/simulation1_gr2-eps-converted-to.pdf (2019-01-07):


10 | 20 | 30 | 40 | 50

# X - Time

300

400

500

600

# Y - PPG Analog Reading (0-1023)

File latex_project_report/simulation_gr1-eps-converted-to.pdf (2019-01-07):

X - Time; Y - PPG Analog Reading

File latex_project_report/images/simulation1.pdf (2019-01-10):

data = {{1, 347}, {2, 264}, {3, 264}, {4, 308}, {5, 316}, {6, 264}, {7, 264}, {8, 376}, {9, 264}, {10, 264}, {11, 264}, {12, 470}, {13, 313}, {14, 264}, {15, 264}, {16, 316}, {17, 264}, {18, 264}, {19, 322}, {20, 264}, {21, 264}, {22, 264}, {23, 331}, {24, 264}, {25, 264}, {26, 264}, {27, 317}, {28, 264}, {29, 264}, {30, 264}, {31, 322}, {32, 264}, {33, 264}, {34, 363}, {35, 264}, {36, 264}, {37, 264}, {38, 387}, {39, 264}, {40, 264}, {41, 272}, {42, 342}, {43, 264}, {44, 264}, {45, 347}, {46, 264}, {47, 264}, {48, 264}, {49, 340}, {50, 264}}; lm = LinearModelFit[data, x, x]

FittedModel - -

Show[ListLinePlot[data, PlotStyle → Blue, PlotMarkers → {Automatic, 6}, GridLines → Automatic], Plot[lm[x], {x, 0, 50}, PlotStyle → Red], AxesLabel → {"X - Time", "Y - PPG Analog Reading (0-1023)"}, PslotLabel → lm["BestFit"]]

Y - PPG Analog Reading (0-1023)

X - Time

data2 = {{1, 265}, {2, 471}, {3, 264}, {4, 264}, {5, 574}, {6, 264}, {7, 264}, {8, 264}, {9, 640}, {10, 264}, {11, 264}, {12, 264}, {13, 558}, {14, 275}, {15, 264}, {16, 264}, {17, 440}, {18, 264}, {19, 264}, {20, 264},
{21, 450}, {22, 264}, {23, 265}, {24, 264}, {25, 466}, {26, 264},
{27, 264}, {28, 264}, {29, 487}, {30, 264}, {31, 264}, {32, 264},
{33, 476}, {34, 280}, {35, 264}, {36, 264}, {37, 446}, {38, 264}, {39, 264}, {40, 264}, {41, 338}, {42, 434}, {43, 265}, {44, 264}, {45, 303}, {46, 333}, {47, 264}, {48, 264}, {49, 307}, {50, 264}};

lm2 = LinearModelFit[data2, x, x]

FittedModel - -

Show[ListLinePlot[data2, PlotStyle → Blue,
PlotMarkers → {Automatic, 6}, PlotRange → {250, 650}, GridLines → Automatic], Plot[lm2[x], {x, 0, 50}, PlotStyle → Red],
AxesLabel → {"X - Time", "Y - PPG Analog Reading (0-1023)"},
PslotLabel → lm["BestFit"]]

X - Time

Y - PPG Analog Reading (0-1023)

2 simulation1.nb

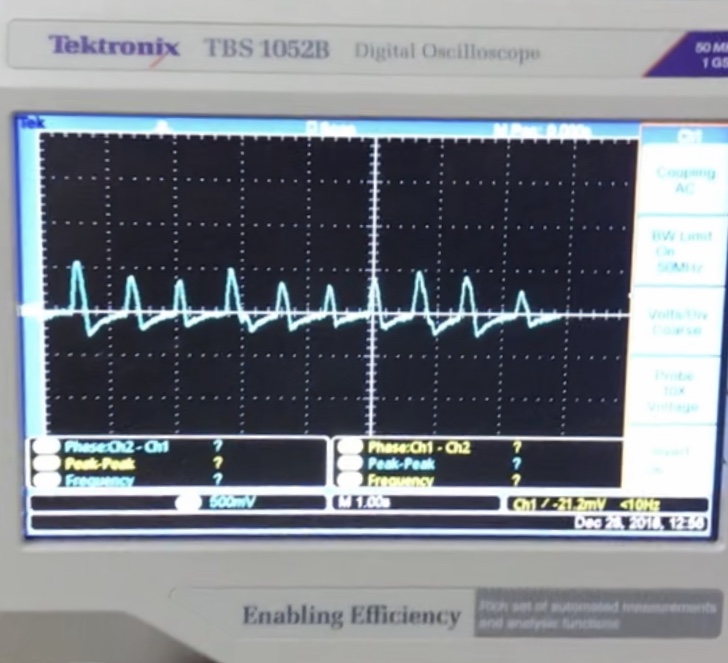
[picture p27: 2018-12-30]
latex_project_report/images/res1.jpg

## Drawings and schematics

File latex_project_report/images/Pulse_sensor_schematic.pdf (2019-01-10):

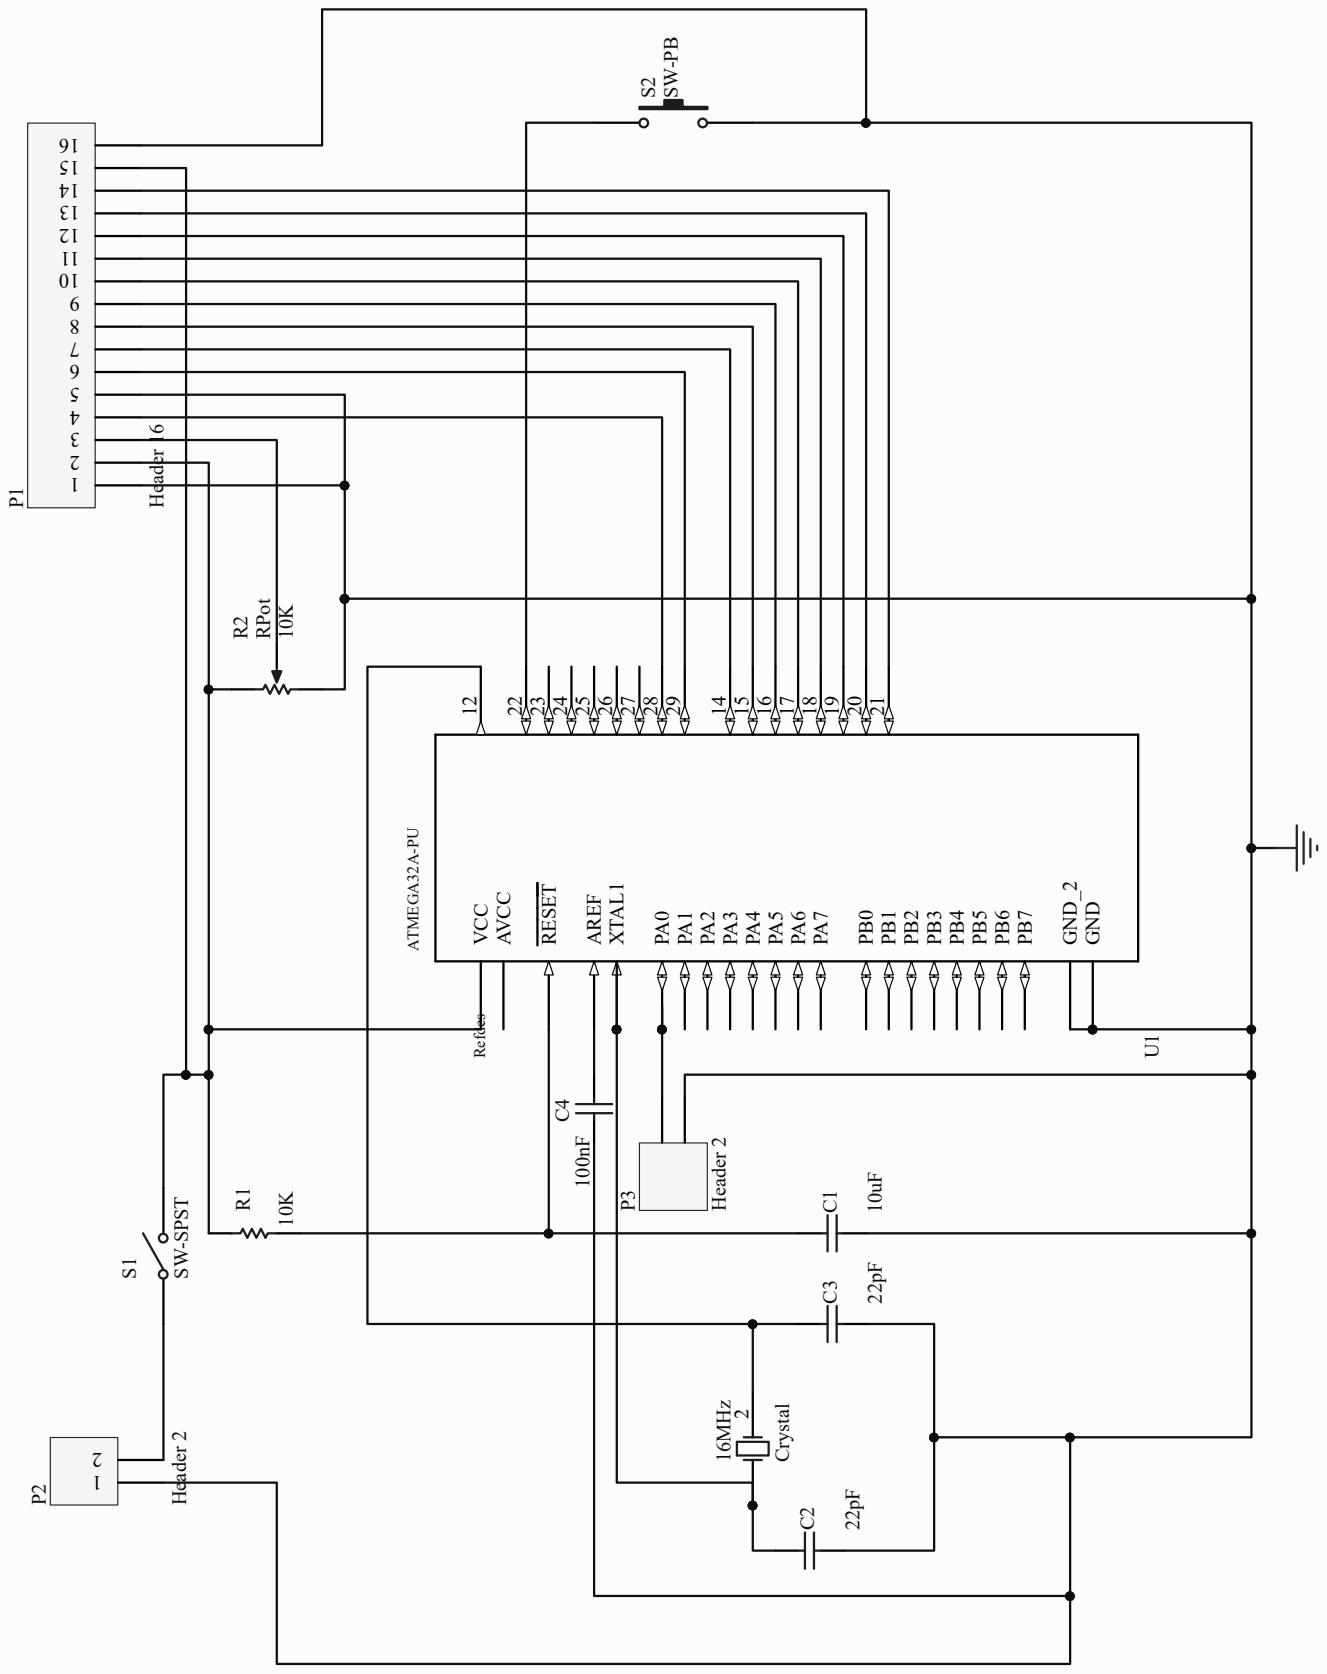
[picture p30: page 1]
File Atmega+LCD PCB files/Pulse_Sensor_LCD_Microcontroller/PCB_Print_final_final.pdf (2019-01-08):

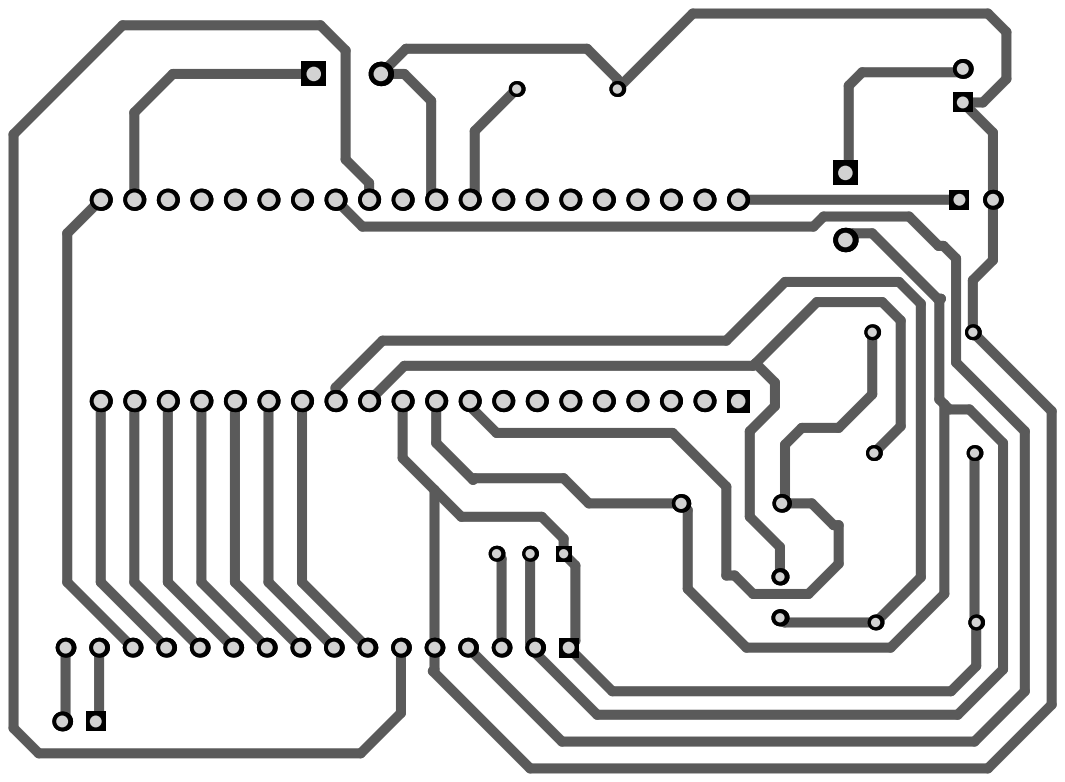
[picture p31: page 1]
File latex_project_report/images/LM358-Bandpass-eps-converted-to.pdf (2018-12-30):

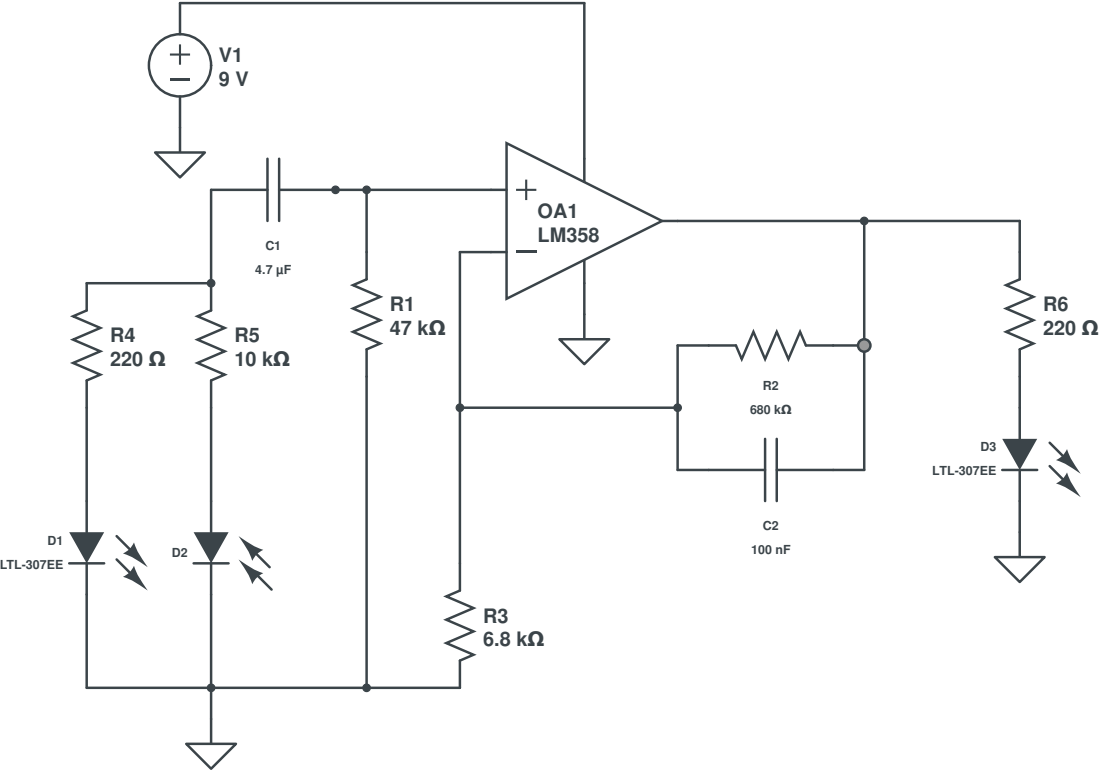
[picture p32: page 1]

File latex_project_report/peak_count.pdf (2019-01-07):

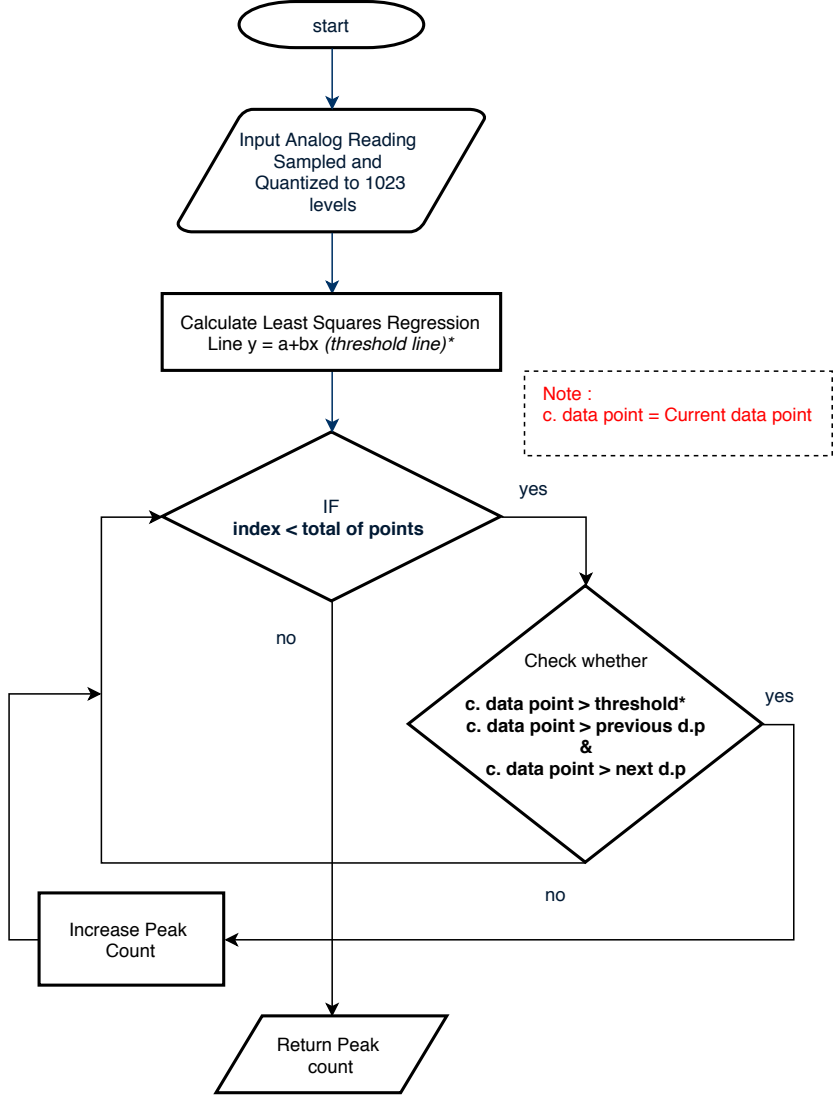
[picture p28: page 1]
start; yes; Check whether; Increase Peak Count; Return Peak count

Input Analog Reading
Sampled and
Quantized to 1023
levels

Calculate Least Squares Regression
Line y = a+bx (threshold line)*

Note :
c. data point = Current data point

index < total of points

c. data point > threshold*
c. data point > previous d.p

& c. data point > next d.p

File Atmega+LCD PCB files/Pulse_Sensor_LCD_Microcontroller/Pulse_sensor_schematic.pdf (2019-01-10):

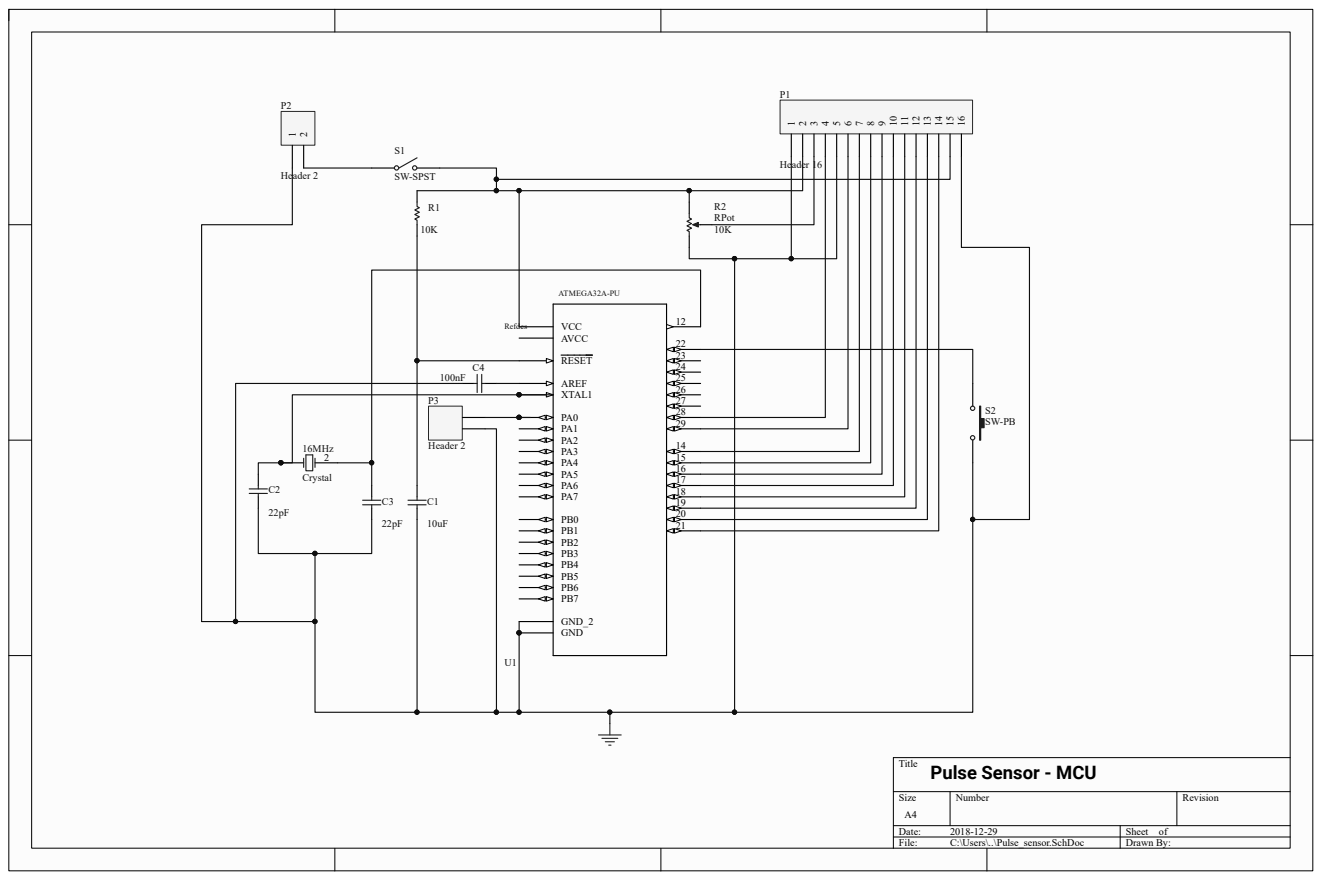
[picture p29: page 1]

16MHz
